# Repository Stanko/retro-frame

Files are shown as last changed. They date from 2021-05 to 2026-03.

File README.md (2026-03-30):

# Retro Frame

DIY pixel art frame, inspired by [Game Frame](https://ledseq.com/product/game-frame/).

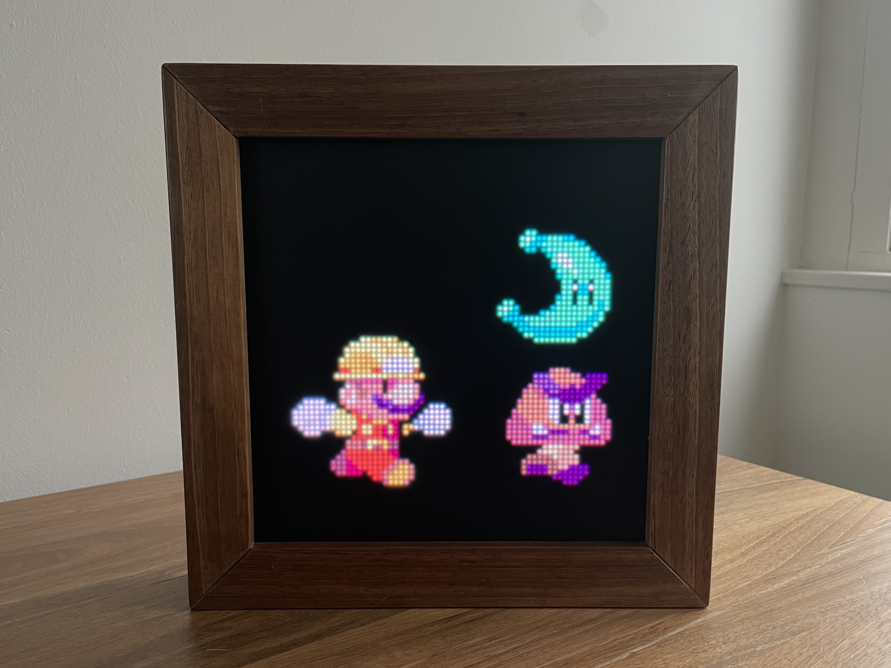
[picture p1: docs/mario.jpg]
Retro Frame photo showing Mario chasing a gumba

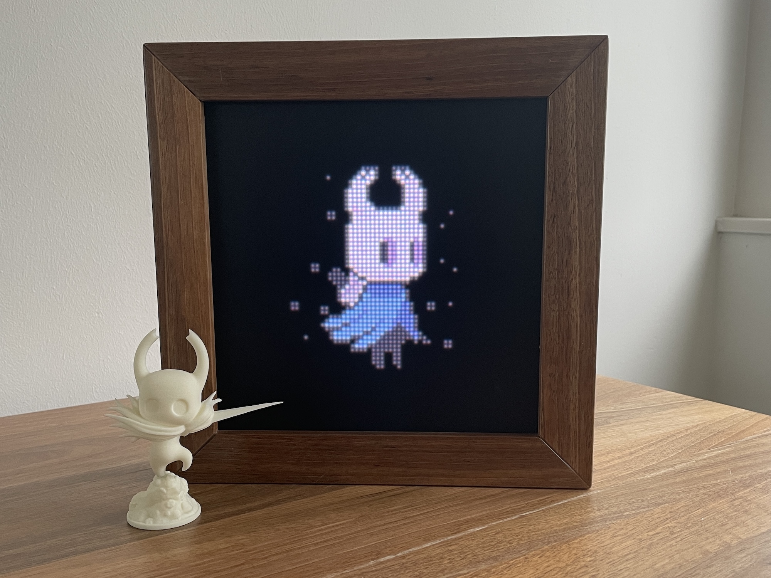
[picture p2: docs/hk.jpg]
Retro Frame photo showing Hollow Knight

<video src="https://github.com/Stanko/retro-frame/assets/776788/32b4b00a-9a80-41c9-9a88-cf3a86338d27"></video>
<video src="https://github.com/Stanko/retro-frame/assets/776788/2ef91225-8ba0-4dff-8bf8-045a9eec68e6"></video>

## Intro

The brain is [Adafruit MatrixPortal M4](https://www.adafruit.com/product/4745), an ESP32-based controller. You'll need to follow Adafruit's documentation to install CircuitPython. Then you can copy the code (don't forget to create src/settings.py).

Files you'll need to copy to your MatrixPortal are:

Rename `src/settings_example.py` to `src/settings.py`. If you want the frame to connect to the internet in order to fetch the correct time, add your network name, password, and set `skip_connection=False`.

Then copy the following files and folders:

- `code.py` and all Python files under `src/` (see `copy.bat|sh`)
- `firmware/[current_version]/lib` to `lib`
- `assets` (which includes splash screen and digital clock sprite)
- `gif` (pick and choose animations you like)

If you are using a Matrix Portal M4 chip, the latest retro-frame version is saved in branch: `v1`

For Matrix Portal S3 chips, use the latest commit from branch `dev`

## Real Time Clock (RTC) Support

The current RTC implementation supports the Adafruit PCF8523 on the shared I2C bus.

Configuration:

- Enable RTC support by setting `real_time=RealTimeSettings(timezone="Europe/Amsterdam", chip_name="PCF8523")`
- If `chip_name` is omitted, the project falls back to the built-in software RTC only

Required CircuitPython libraries for PCF8523 support:

- `adafruit_pcf8523` package
- `adafruit_bus_device`
- `adafruit_register`

Behavior:

- On boot, Retro Frame tries to read time from the external RTC
- The external RTC is only trusted after the device has completed at least one successful online sync
- That trust flag is stored internally in `microcontroller.nvm`, not in user settings and not in the filesystem
- If the trust flag is missing, the stored RTC time is ignored until the first successful online sync
- After a successful online sync, Retro Frame updates:
  - the built-in CircuitPython runtime RTC (`RTC().datetime`)
  - the external PCF8523 RTC
  - the internal `microcontroller.nvm` sync flag

Update cycle:

- If the hardware clock has been updated once and the flag is set, no further automatic syncs are made. You can use Retro-Frame completely offline.
- If retro frame is connected, pressing the main action button while either clock app is active also triggers an immediate online refresh and saves the latest time into the hardware clock.
- On star-up, the hardware clock is printed on console for debugging.
- If the hardware clock continue to lose time, check the battery.

Fallback behavior:

- If the PCF8523 hardware is not connected, not configured, or its libraries are missing, the system falls back to software RTC only
- In software-only mode, time is still fetched from the network when Wi-Fi is available
- If stored hardware RTC time looks wrong after it has been trusted, the current implementation will still use it; check the RTC backup battery in that case

## Hardware Addresses

If your hardware uses different I2C addresses, update them in `src/settings.py` (see `src/settings_example.py` for the expected structure).

Common defaults in this project:

- LIS3DH accelerometer: `0x19`
- Seesaw rotary encoder: `0x36`

Relevant settings are:

- `accelerometer=AccelerometerSettings(address=0x19)`
- `rotary_encoder=RotaryEncoderSettings(enabled=True, address=0x36, button_pin=24)`

If you are not sure what address your Seesaw encoder is using, run the I2C Seesaw diagnostic and read the detected address from serial output.

## Apps

There are four apps:

- Gif player (runs each animation for 5 minutes then switches to the next one)
- Digital clock
- Analogue clock
- Blank - used to preserve power during the night

Without an external RTC, the clock apps need internet access to get correct time after boot. With a configured PCF8523 that has already been synced once, the clocks can start from stored RTC time and then refresh online later.

By default, the display will switch to the digital clock at 23:30, to blank at midnight, and to gif player at 8:30 in the morning. Check [src/settings_example.py](./src/settings_example.py), copy it to src/settings.py, and update it to your preferences.

### Controls

Tilting the display **left** and **right** will cycle between the apps (button up will do the same).

Tilting the display **back** and **forward** will (button down will do the same):

- Gif app - switch between gifs
- Digital clock - switch between 12 and 24 hours clock modes
- Digital clock / Analogue clock - force an immediate online time refresh

| Digital Clock | Analogue Clock |
| --- | --- |
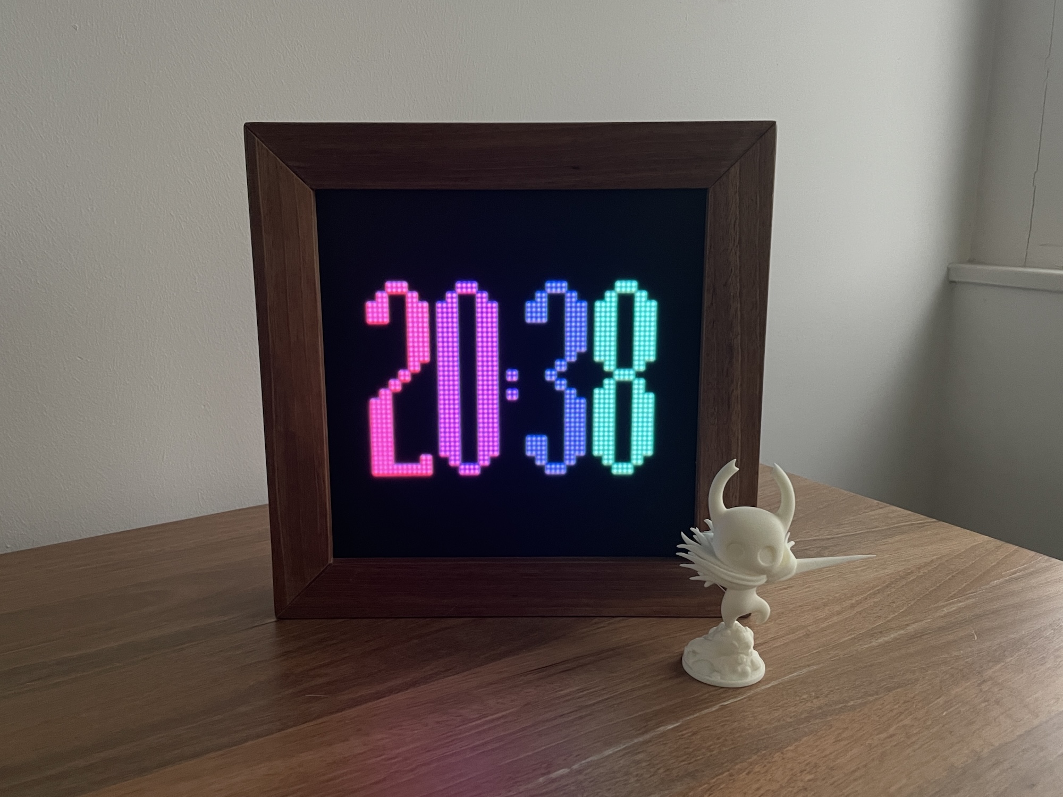
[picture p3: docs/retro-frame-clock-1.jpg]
Retro Frame with digital clock app showing
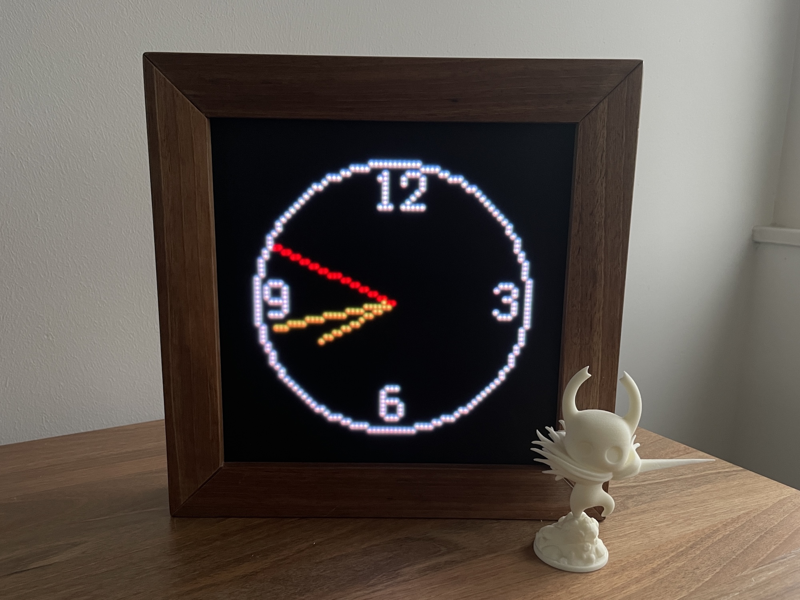
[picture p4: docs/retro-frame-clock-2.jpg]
Retro Frame with analogue clock app showing
|  |  |

## List of parts

This is a list of all of the main parts with the links to the ones we used.

- Adafruit MatrixPortal M4 https://www.adafruit.com/product/4745
- 64x64 RGB LED Matrix - 2.5mm Pitch - 1/32 Scan - https://www.adafruit.com/product/3649 or https://www.aliexpress.com/item/32816409052.html
- LED diffuser - https://www.adafruit.com/product/4594
- USB C charger - I had one lying around
- The display fits into the IKEA SANNAHED picture frame. But check [frame-v2.png](./random-backup-files/frame/frame-v2.png) for a custom frame blueprints.
- USB C cable - https://www.aliexpress.com/item/1005002105030431.html
- You can control the display by tilting it, but if you want to add buttons, I used these in the first version - https://www.aliexpress.com/item/4000043687021.html
- [3D printed hooks](./random-backup-files/frame/hook.png) for the rubber band that presses the display against the diffuser. Code for generating the model is [here](./random-backup-files/frame/hook.js).

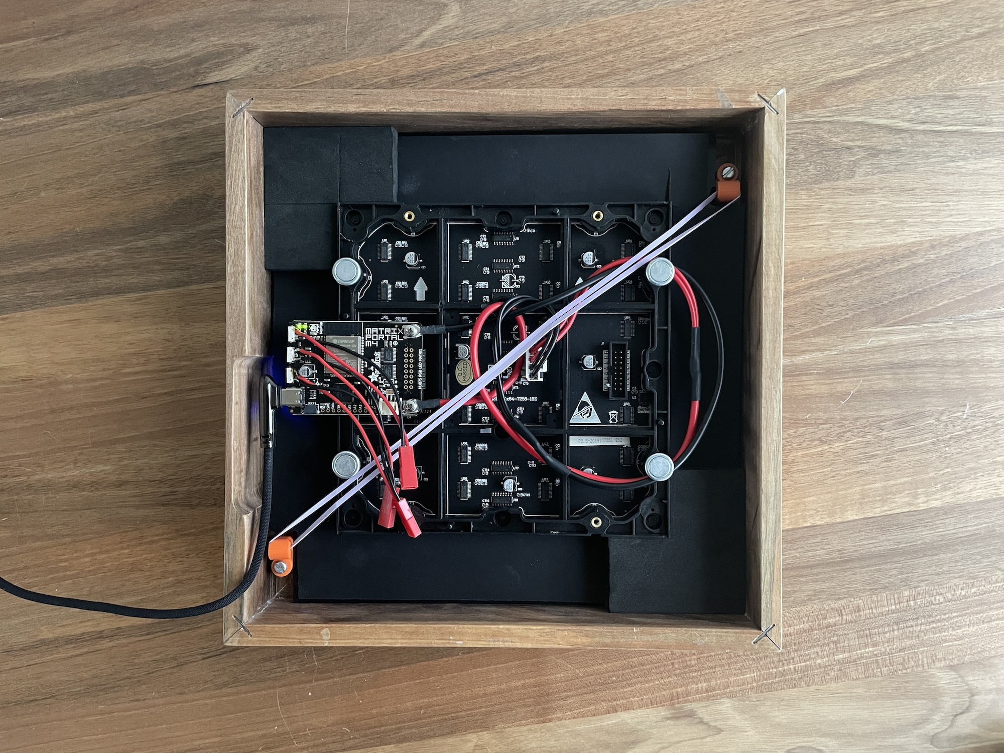
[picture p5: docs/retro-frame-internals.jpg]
Retro Frame internals


## Similar projects

There is a few similar projects you might want to check out:

- https://github.com/hanneslinder/esp-pixel-matrix
- https://www.youtube.com/watch?v=A5A6ET64Oz8

## Art credits

If I included your art and you want it removed, I'm sorry, just open an issue and I'll take care of it. The only reason I included your work in the first place is because it is awesome and it makes me happy.

### Other people:

- [Bear](https://rephildesign.tumblr.com/post/120859307063/filbertgames-this-is-what-happens-when-you)
- [Bunny](https://x.com/ko_dll/status/1792974719563485218)
- [Dog](https://dribbble.com/shots/2367354-Doggy-Rabbit)
- [Dota emojis (diretide, giff, es)](https://dota2.fandom.com/wiki/Emoticons)
- Earth and Moon - generated using wonderful [PixelPlanets](https://github.com/Deep-Fold/PixelPlanets)
- [Ember Spirit](https://33.media.tumblr.com/3f53a2565f16799b155d33072ef5fca0/tumblr_nalmwaJGah1sgajexo2_250.gif)
- [Firepit](https://old.reddit.com/r/PixelArt/comments/7d0y1p/oc_fireplace_animation/)
- [Fox](https://elthen.itch.io/2d-pixel-art-fox-sprites)
- [Hollow Knight](https://www.deviantart.com/haykira/art/Hallownest-Fellas-841502305)
- [Jim](https://hani-amir.com/blog/2017/2/7/pixel-art-animation-basics-5-classic-side-scrolling-walking-running-animations-from-the-snes-era)
- [Link](https://www.deviantart.com/world-of-noel/art/Linked-Seasons-Link-361192040)
- [Madeline](https://rephil.dribbble.com/)
- [Mario chase](https://rephil.dribbble.com/)
- [Mario jumping](https://pug-of-war.tumblr.com/post/116535010016/its-a-me-ah-mario)
- [Mega Man](https://www.deviantart.com/bionicandrew1/art/MegaMan-MvC-Moves-736040903)
- [Nyan cat](https://www.nyan.cat/credits.php)
- [Ori](https://twitter.com/WoostarsPixels/status/1543954734108872705?cxt=HHwWgsC8vdCpne0qAAAA)
- [Rafael](https://adamklingpixel.weebly.com/)
- [Robin](http://www.playiconoclasts.com/)
- [Spinning skull](https://www.artstation.com/artwork/ykRDB3)
- [The One Ring](https://dribbble.com/shots/3273233-The-One-Ring)
- [Tears of the Kingdom](https://www.pixeljess.com/portfolio)
- [WC2 Footman](https://old.reddit.com/r/warcraft3/comments/f3b6fw/warcraft_2_footman_remaster/)

### Myself

- Splash screen
- Clock digits
- [Pulsar](https://muffinman.io/pulsar) animations
- Totoro - heavily inspired by [this one](https://www.deviantart.com/andrewjohnnnn/art/Totoro-Rain-GIF-613239881)
- Tutur, in loving a memory of Artur <3

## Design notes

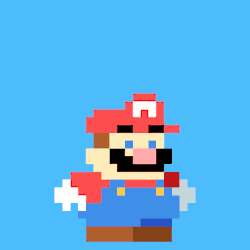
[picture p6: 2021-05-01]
random-backup-files/original-gifs/mario-jump.gif

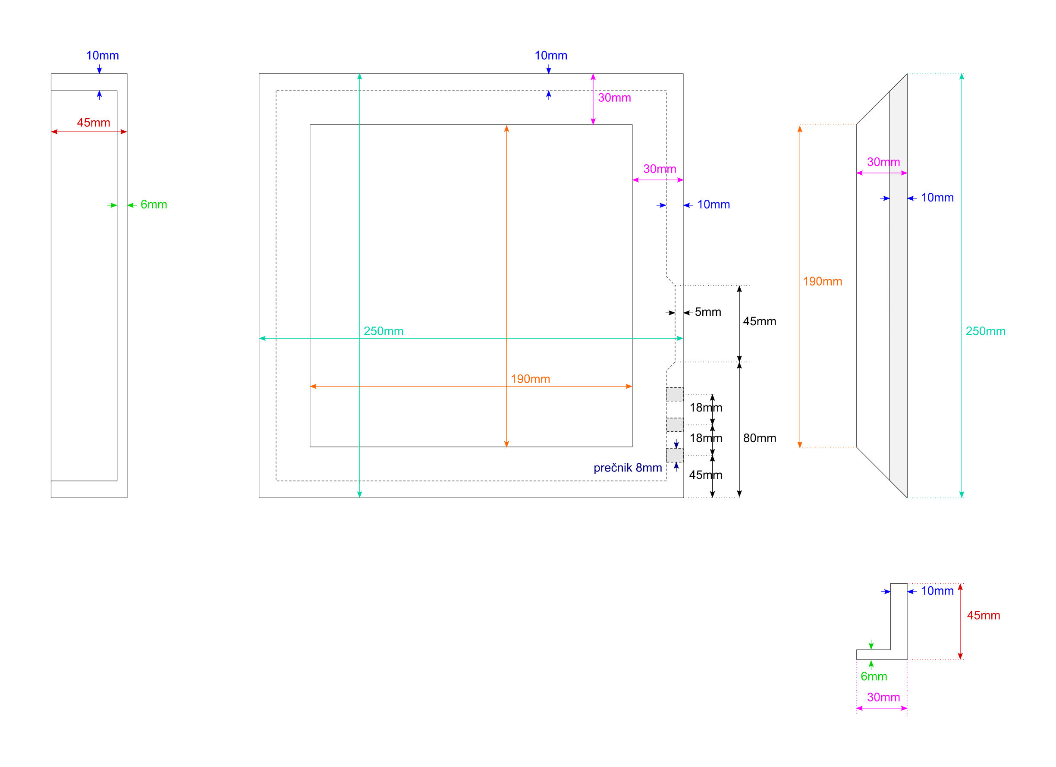
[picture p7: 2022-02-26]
random-backup-files/frame/frame-v1.png

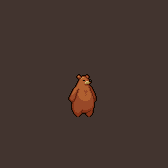
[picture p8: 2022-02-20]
random-backup-files/original-gifs/bear.gif

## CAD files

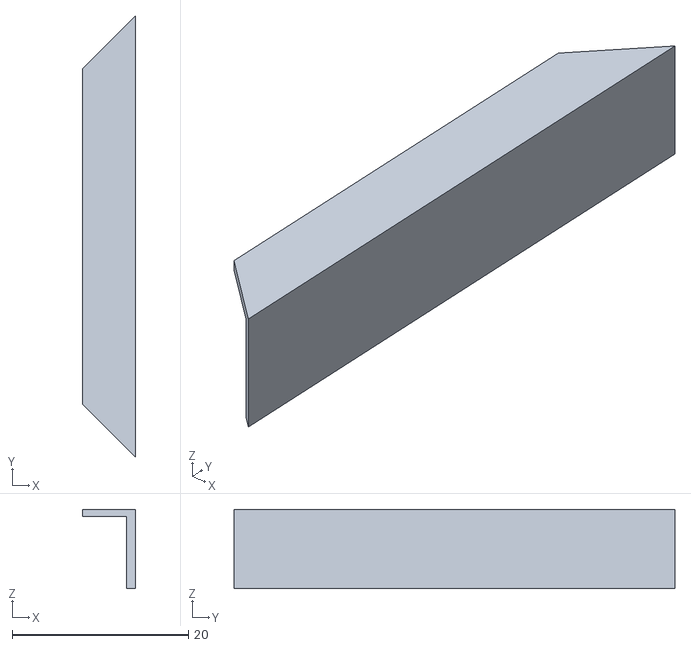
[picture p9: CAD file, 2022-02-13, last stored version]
frame/profile.stl
6.00 x 50.0 x 9.00

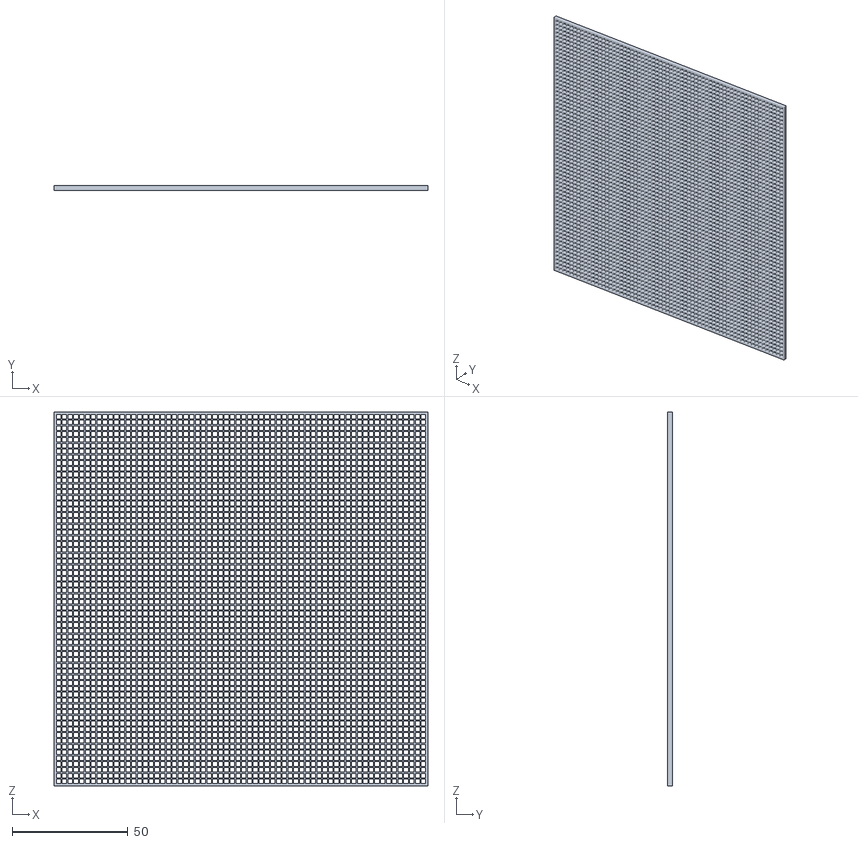
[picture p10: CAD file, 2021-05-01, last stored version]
grid.stl
161.5 x 2.00 x 161.5

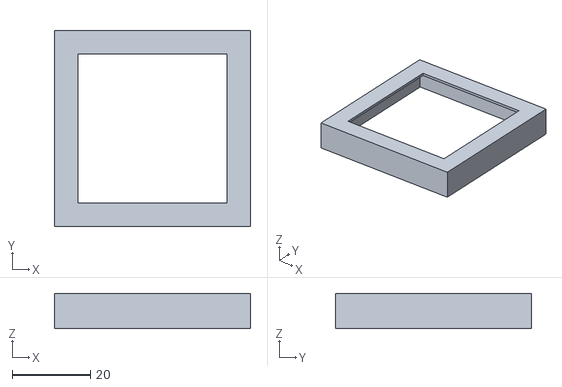
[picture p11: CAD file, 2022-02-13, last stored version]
frame/frame.stl
50.0 x 50.0 x 9.00

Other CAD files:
frame/frame.blend
frame/profile.blend

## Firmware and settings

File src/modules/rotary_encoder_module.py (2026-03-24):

try:
    from adafruit_seesaw import digitalio as seesaw_digitalio
    from adafruit_seesaw import rotaryio as seesaw_rotaryio
    from adafruit_seesaw import seesaw
except ImportError:
    seesaw = None
    seesaw_digitalio = None
    seesaw_rotaryio = None

from src.modules.button_module import ButtonModule


class RotaryEncoderModule:
    def __init__(self, i2c, address=0x36, button_pin=24):
        if seesaw is None or seesaw_digitalio is None or seesaw_rotaryio is None:
            raise RuntimeError("adafruit_seesaw is not installed on the device.")

        self.device = seesaw.Seesaw(i2c, addr=address)
        self.device.pin_mode(button_pin, self.device.INPUT_PULLUP)
        self.button = ButtonModule(
            button_input=seesaw_digitalio.DigitalIO(self.device, button_pin),
            active_low=True,
        )
        self.encoder = seesaw_rotaryio.IncrementalEncoder(self.device)
        self.last_position = -self.encoder.position

    def read_delta(self) -> int:
        position = -self.encoder.position
        delta = position - self.last_position
        self.last_position = position
        return delta

    def is_pressed(self) -> bool:
        return self.button.is_pressed()

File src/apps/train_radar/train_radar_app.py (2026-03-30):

import math
import time

from adafruit_bitmap_font import bitmap_font
from adafruit_display_shapes.line import Line
from adafruit_display_text import label
from displayio import Bitmap, Group, Palette, TileGrid

from src.base_app import BaseApp
from src.apps.train_radar.animated_chevron_row import AnimatedChevronRow, AnimatedChevronRowConfig
from src.apps.train_radar.data_polling import DataPolling
from src.apps.train_radar.models import (
    RadarHalfPanelConfig,
    RadarPanelState,
    TrainRadarAnimationConfig,
    TrainRadarConfig,
    TrainRadarContentConfig,
    TrainRadarDisplayConfig,
    TrainRadarPanelLayoutConfig,
    TrainRadarStyleConfig,
)
from src.ui.scrolling_line import ScrollingLine


MOCK = None


TRAIN_RADAR_CONFIG = TrainRadarConfig(
    display=TrainRadarDisplayConfig(
        font_glyphs=b" '()&+,-./0123456789:;<>?=ABCDEFGHIJKLMNOPQRSTUVWXYZ_abcdefghijklmnopqrstuvwxyz",
        font_path="/assets/4by6.bdf",
        frame_interval_seconds=0.05,
        layout_refresh_seconds=1.0,
        divider_color=0x202020,
    ),
    panel_layout=TrainRadarPanelLayoutConfig(
        font_height=6,
        padding=1,
        line_gap=2,
        panel_width=64,
        badge_size=6,
        badge_gap=1,
        badge_hidden_x=-10,
        badge_y=0,
    ),
    animation=TrainRadarAnimationConfig(
        chevron_count=3,
        chevron_interval_seconds=0.25,
        chevron_spacing=6,
    ),
    style=TrainRadarStyleConfig(
        upcoming_line_colors=(
            0xFF3D00,
            0x999999,
            0xFFFFFF,
            0x999999,
        ),
        current_line_colors=(
            0xFFFFFF,
            0xFFFFFF,
            0xFF3D00,
            0xFFFFFF,
        ),
        company_icon_colors={
            "NS": (0xFFD400, 0x003082),
            "ICE": (0xFFFFFF, 0xDB0011),
            "NS_INT": (0xFFFFFF, 0x003082),
        },
    ),
    content=TrainRadarContentConfig(
        station_label_replacements={
            "Amsterdam Centraal": "Amsterdam",
            "Rotterdam Centraal": "Rotterdam",
            "Eindhoven Centraal": "Eindhoven",
            "Frankfurt (M) Hbf": "Frankfurt",
            "Driebergen-Zeist": "Driebergen-Z",
            "Utrecht Centraal": "Utrecht",
        },
        right_chevron_symbol="<",
        left_chevron_symbol=">",
        company_badge_pixels=(
            (0, 0, 1, 2, 0, 0),
            (0, 1, 1, 2, 2, 0),
            (1, 1, 1, 2, 2, 2),
            (1, 1, 1, 2, 2, 2),
            (0, 1, 1, 2, 2, 0),
            (0, 0, 1, 2, 0, 0),
        ),
    ),
)


class RadarHalfPanel:
    ALIGN_LEFT = "left"
    ALIGN_RIGHT = "right"

    def __init__(self, font, config):
        self.font = font
        self.config = config
        self.top_y = config.top_y
        self.scroll_direction = config.scroll_direction
        self.layout = config.layout
        self.animation = config.animation
        self.content = config.content

        self.render_state = RadarPanelState(line_colors=config.initial_line_colors)

        self.company_badge_palette = Palette(3)
        self.company_badge_palette[0] = 0x000000
        self.company_badge_palette[1] = 0x000000
        self.company_badge_palette[2] = 0x000000
        self.company_badge_palette.make_transparent(0)

        self.company_badge = TileGrid(
            self._build_company_badge_bitmap(),
            pixel_shader=self.company_badge_palette,
            x=self.layout.badge_hidden_x,
            y=self.top_y + self.layout.padding + self.layout.badge_y,
        )
        self.header_label = label.Label(
            font,
            text="",
            color=config.initial_line_colors[0],
            x=0,
            y=self.y_pos_by_line_index(0),
        )
        self.origin_line = ScrollingLine(
            font,
            config.initial_line_colors[1],
            text="",
            x=self.layout.padding,
            y=self.y_pos_by_line_index(1),
            align=ScrollingLine.ALIGN_CENTER,
            width=self.layout.content_width,
            scroll_direction=self.scroll_direction,
        )
        self.middle_row = AnimatedChevronRow(
            font,
            AnimatedChevronRowConfig(
                line_y=self.y_pos_by_line_index(2),
                content_x=self.layout.padding,
                content_width=self.layout.content_width,
                align=config.align,
                chevron_symbol=config.chevron_symbol,
                initial_text_color=config.initial_line_colors[0],
                initial_chevron_color=config.initial_line_colors[2],
                chevron_count=self.animation.chevron_count,
                step_interval_seconds=self.animation.chevron_interval_seconds,
                character_spacing=self.animation.chevron_spacing,
                reserved_middle_text="-60s",
            ),
        )
        self.destination_line = ScrollingLine(
            font,
            config.initial_line_colors[3],
            text="",
            x=self.layout.padding,
            y=self.y_pos_by_line_index(3),
            align=ScrollingLine.ALIGN_CENTER,
            width=self.layout.content_width,
            scroll_direction=self.scroll_direction,
        )

    def add_to_group(self, group: Group) -> None:
        group.append(self.company_badge)
        group.append(self.header_label)
        self.origin_line.add_to_group(group)
        self.middle_row.add_to_group(group)
        self.destination_line.add_to_group(group)

    def render(self, state: RadarPanelState) -> None:
        self.render_state = state

        self._apply_line_colors(state.line_colors)
        self._apply_company_badge_colors(state.company_badge_colors)
        self.header_label.text = state.header_text
        self._align_header()
        self.origin_line.set_text(state.origin_text)
        self.middle_row.render(state.middle_text, state.show_chevron, state.animate_chevrons)
        self.destination_line.set_text(state.destination_text)

    def update(self, now: float) -> None:
        self.origin_line.update(now)
        self.destination_line.update(now)
        self.middle_row.update(now)

    def y_pos_by_line_index(self, line_index: int) -> int:
        half_font_height = int(self.layout.font_height / 2)
        if line_index == 0:
            return self.top_y + self.layout.padding + half_font_height

        line_height = self.layout.font_height + self.layout.line_gap
        return self.top_y + self.layout.padding + half_font_height + (line_height * line_index)

    def _align_header(self) -> None:
        text_width = self.header_label.bounding_box[2]
        badge_colors = self.render_state.company_badge_colors
        if badge_colors is None:
            self.company_badge.x = self.layout.badge_hidden_x
            self.header_label.x = self.layout.padding + int((self.layout.panel_width - text_width) / 2)
            return
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

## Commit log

2022-02-13 v1 I guess
    [frame.blend, frame.stl, grid.stl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]
2022-02-14 Small performance updates. Auto switch to clock at midnight.
2023-02-04 Circuitpython 7.3.3
2023-08-07 Add firmware folder + circuitpython 8.2.2 and lib bundle
2023-08-07 Fix exception raise for BaseApp
    [base_app.py]
2023-08-07 Prevent error when no bitmaps are loaded into device
2023-08-07 Add erase firmware
    The erase_m4.uf2 file load all zeros into all of flash, skipping the bootloader section. It writes 512k-16k of zeros starting at 16k. It is useful for clearing out damaged CIRCUITPY filesystems in internal flash.
2023-08-07 Re-do network connection to save memory
    By not using the Network class from adafruit, we are saving 50kb of SRAM memory. This means we can use both network connectivity and the GifPlayerApp without running into OutOfMemory errors.
    [network_module.py]
2023-08-07 Decouple device time update from ClockApp
    ClockApp should just use the localtime from the hardware and don't have to worry about updating the device time.
    The device time update has been moved to RealTimeClockModule and it is not responsibility of the RetroFrame class.
2023-08-07 Fix bug preventing gif images to change
    [gif_player_app.py]
2023-08-20 Sync time before scheduled switching to clock
2023-08-22 Bring back width_height_from_bitmap
    Unfortunately, if the bitmap does not contain the tile dimensions in the filename, the code was breaking.
    dota-diretide.bmp is 32x256, without this code, the height will be set to 256.
    Deleting only this function is also inconsistent with `frame_count_from_bitmap` that uses the same logic to count the number of tiles in the tilesheet.
    We can't remove the LoopImagesApp yet because of the splash screen.
2024-01-29 Add accelerometer module and event handling
    - Right/Left advances or recedes the current app
    - Front/back is propagated down to the apps for custom behavior
2024-02-02 Moved a lot of files around
    [frame.blend, frame.stl, profile.blend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]
2026-03-24 Replace WorldTime API with timeapi.io
    [real_time_module.py, settings_example.py, settings_utils.py]
2026-03-30 Add i2c diagnostic hint in code.py
2026-03-30 Implement TrainRadar app
    - Refresh when local time smaller or equal to 0
    - Refactor Scrolling line to its own file
    - Truncate Eindhoven Centraal to Eindhoven
    - Update header for current trains
    - Add underscore to the list of available characters
2026-11-07 Avoid reading microprocessor bit every frame
